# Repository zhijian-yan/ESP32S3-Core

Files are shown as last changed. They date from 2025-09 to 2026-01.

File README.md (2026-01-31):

<h1 align="center">ESP32S3-Core</h1>

<p align="center">
<a href="README.md">English</a> | <a href="README_zh.md">简体中文</a>
</p>

<p align="center">
Core board based on Espressif ESP32-S3 module
</p>

<p align="center">
Prototype verified, schematic and Gerber files included — ready for PCB fabrication!🚀🚀🚀
If you find it useful, please consider giving it a star!☝️
</p>

## Features

* Dual-layer PCB design
* All GPIOs are fully broken out, with pin layout compatible with Espressif official ESP32-S3 development boards
* Onboard 160×80 resolution LCD display, backlight brightness controlled by `GPIO9`
* Onboard TF (microSD) card slot, sharing the same SPI bus with the LCD
* LCD and TF card are connected to a full-speed SPI bus routed via IOMUX, supporting up to `80 MHz` clock
* Onboard WS2812B RGB LED driven by `GPIO38`
* USB-to-UART bridge: CH340K, supporting baud rates up to `2 Mbps`
* 5V pin supports both input and output; USB Type-C interface protected by a Schottky diode
* Compact form factor, all resistors and capacitors use 0402 packages

## Silkscreen Labels

* `RST` : Reset button
* `BOOT` : Boot mode selection button
* `PWR` : Power indicator LED
* `TX` : UART transmit indicator LED
* `RX` : UART receive indicator LED
* `USB` : USB Type-C port for full-speed USB communication
* `COM` : USB Type-C port for UART flashing and debugging

## Pin Configuration

> Note: The LCD and TF card share the same SPI bus

| Function | Signal | GPIO |
|---|---|---|
| LCD | LCD_SCLK | IO12 |
| LCD | LCD_MOSI | IO11 |
| LCD | LCD_CS | IO10 |
| LCD | LCD_DC | IO21 |
| LCD | LCD_RST | IO14 |
| LCD | LCD_BL | IO9  |
| TF Card  | TF_SCLK | IO12 |
| TF Card  | TF_MOSI | IO11 |
| TF Card  | TF_MISO | IO13 |
| TF Card  | TF_CS | IO8  |
| UART | TXD0 | IO43 |
| UART | RXD0 | IO44 |
| USB | USB_D- | IO19 |
| USB | USB_D+ | IO20 |
| RGB LED  | RGB | IO38 |

## Hardware Overview

### Board Photo

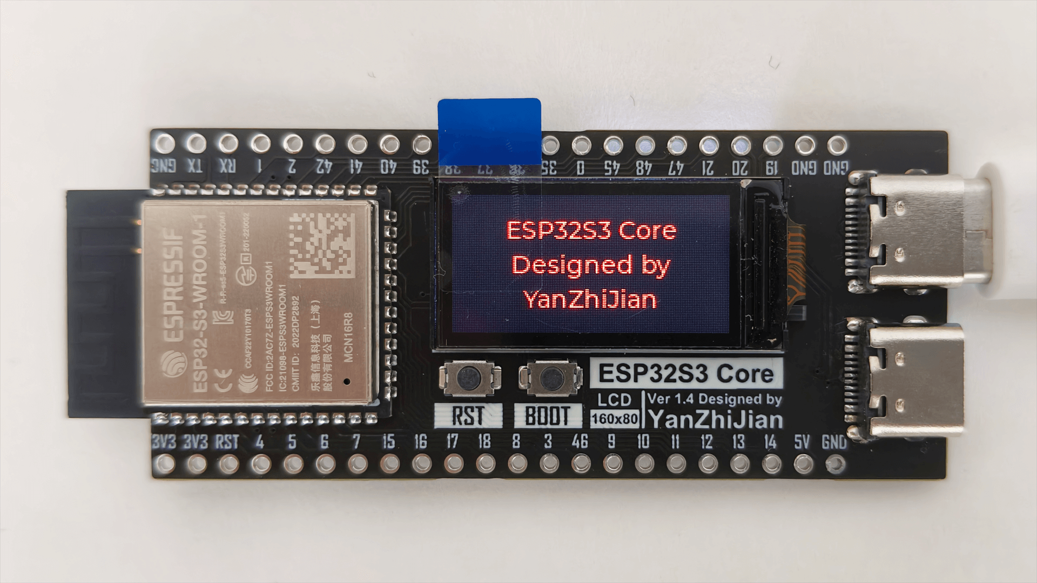
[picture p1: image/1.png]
Board Photo


### Schematic

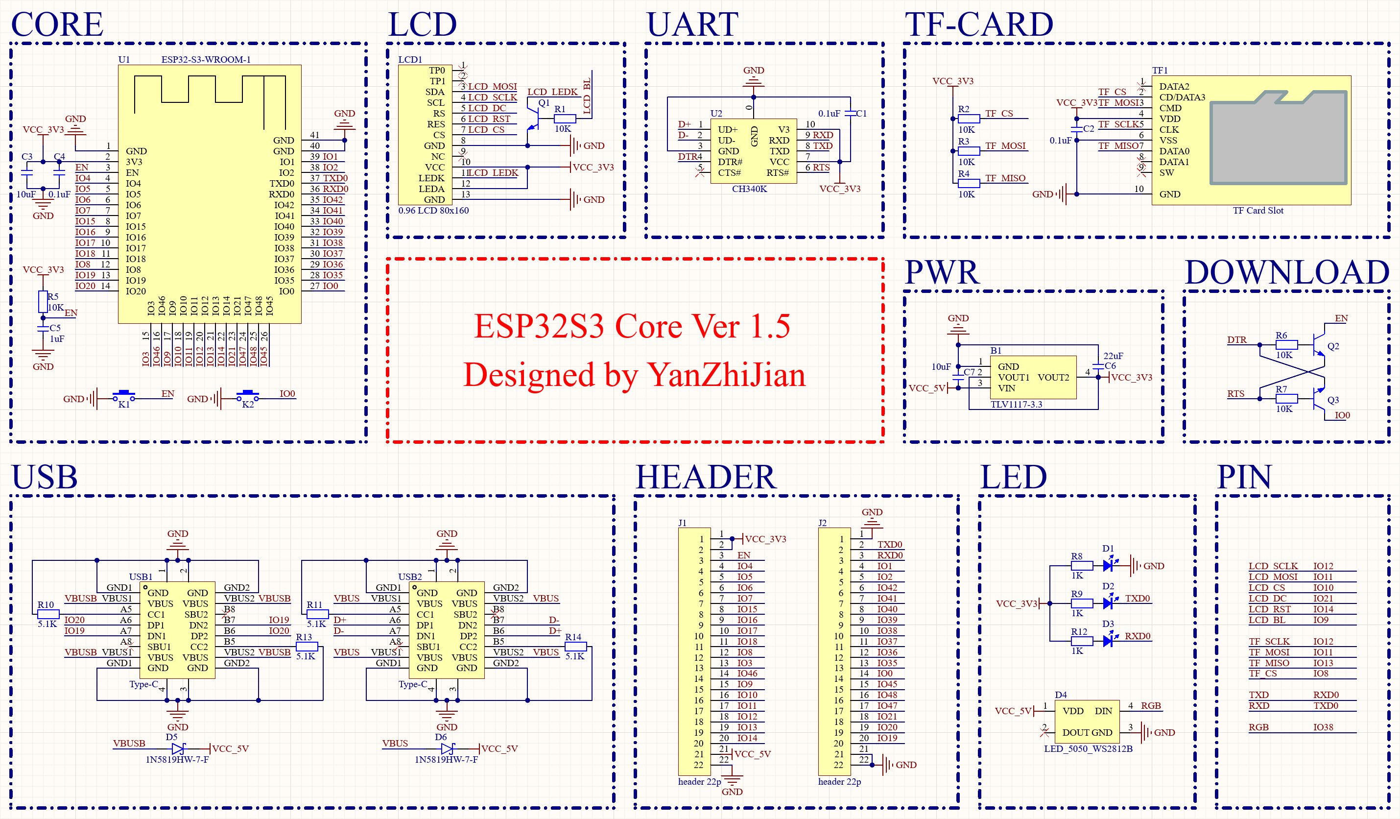
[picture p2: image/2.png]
Schematic


### PCB Layout

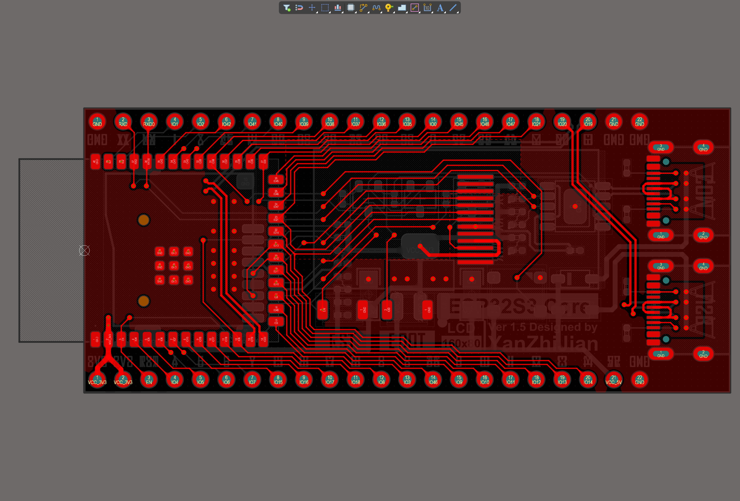
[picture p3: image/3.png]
Top Layer
  
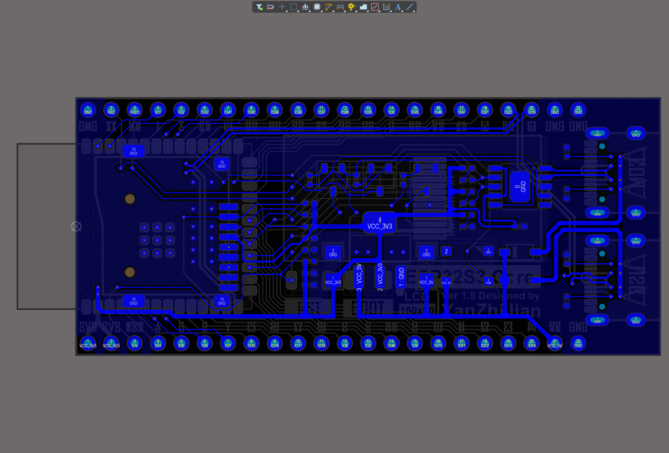
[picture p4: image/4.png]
Bottom Layer


### 3D Model

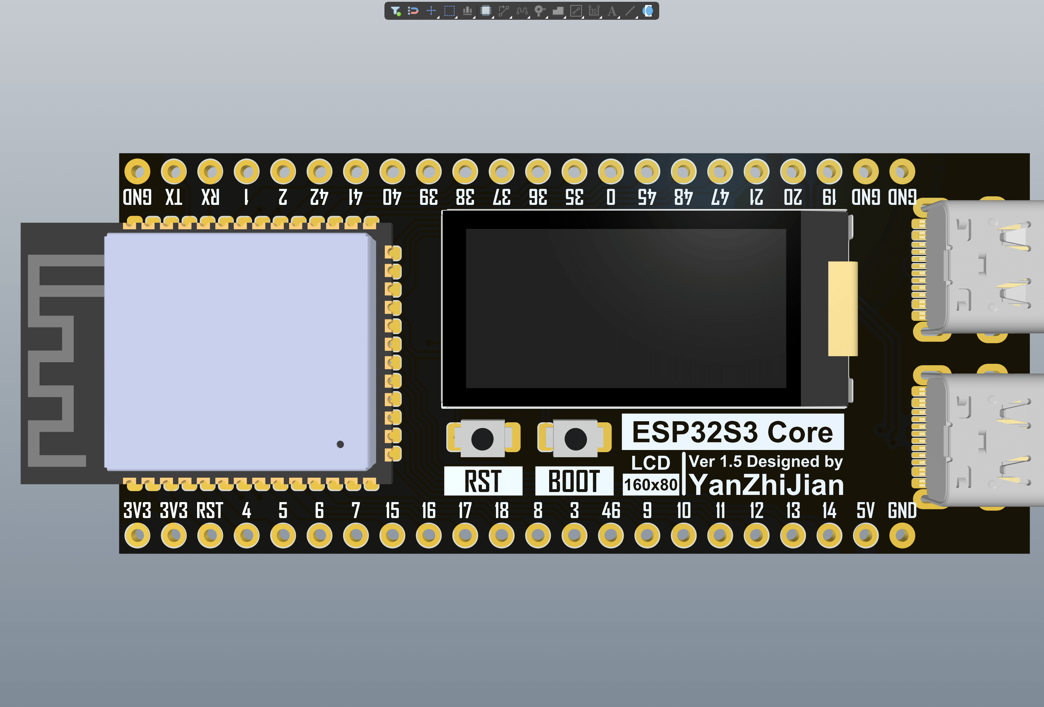
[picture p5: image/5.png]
Top View
  
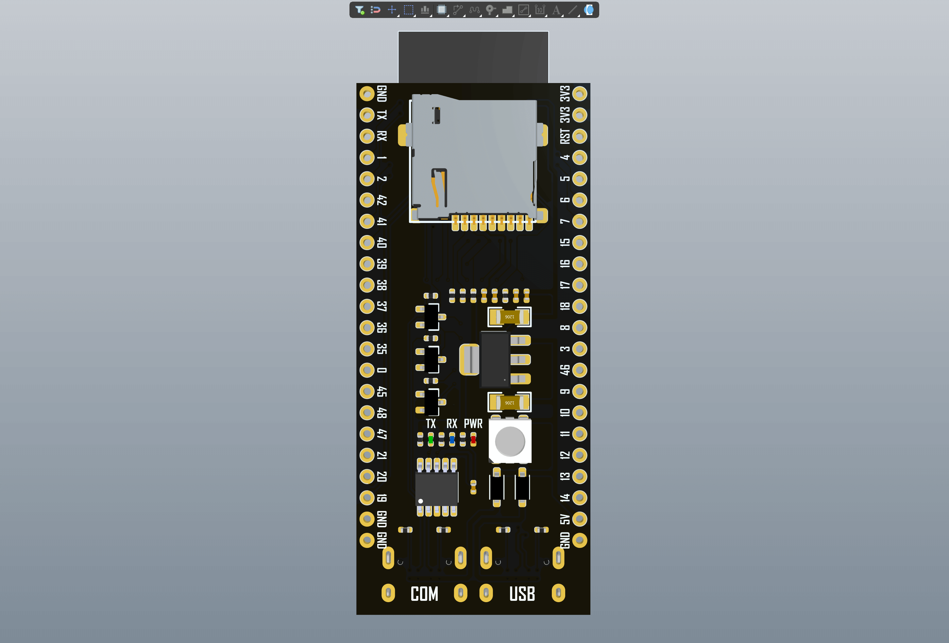
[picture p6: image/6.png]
Bottom View


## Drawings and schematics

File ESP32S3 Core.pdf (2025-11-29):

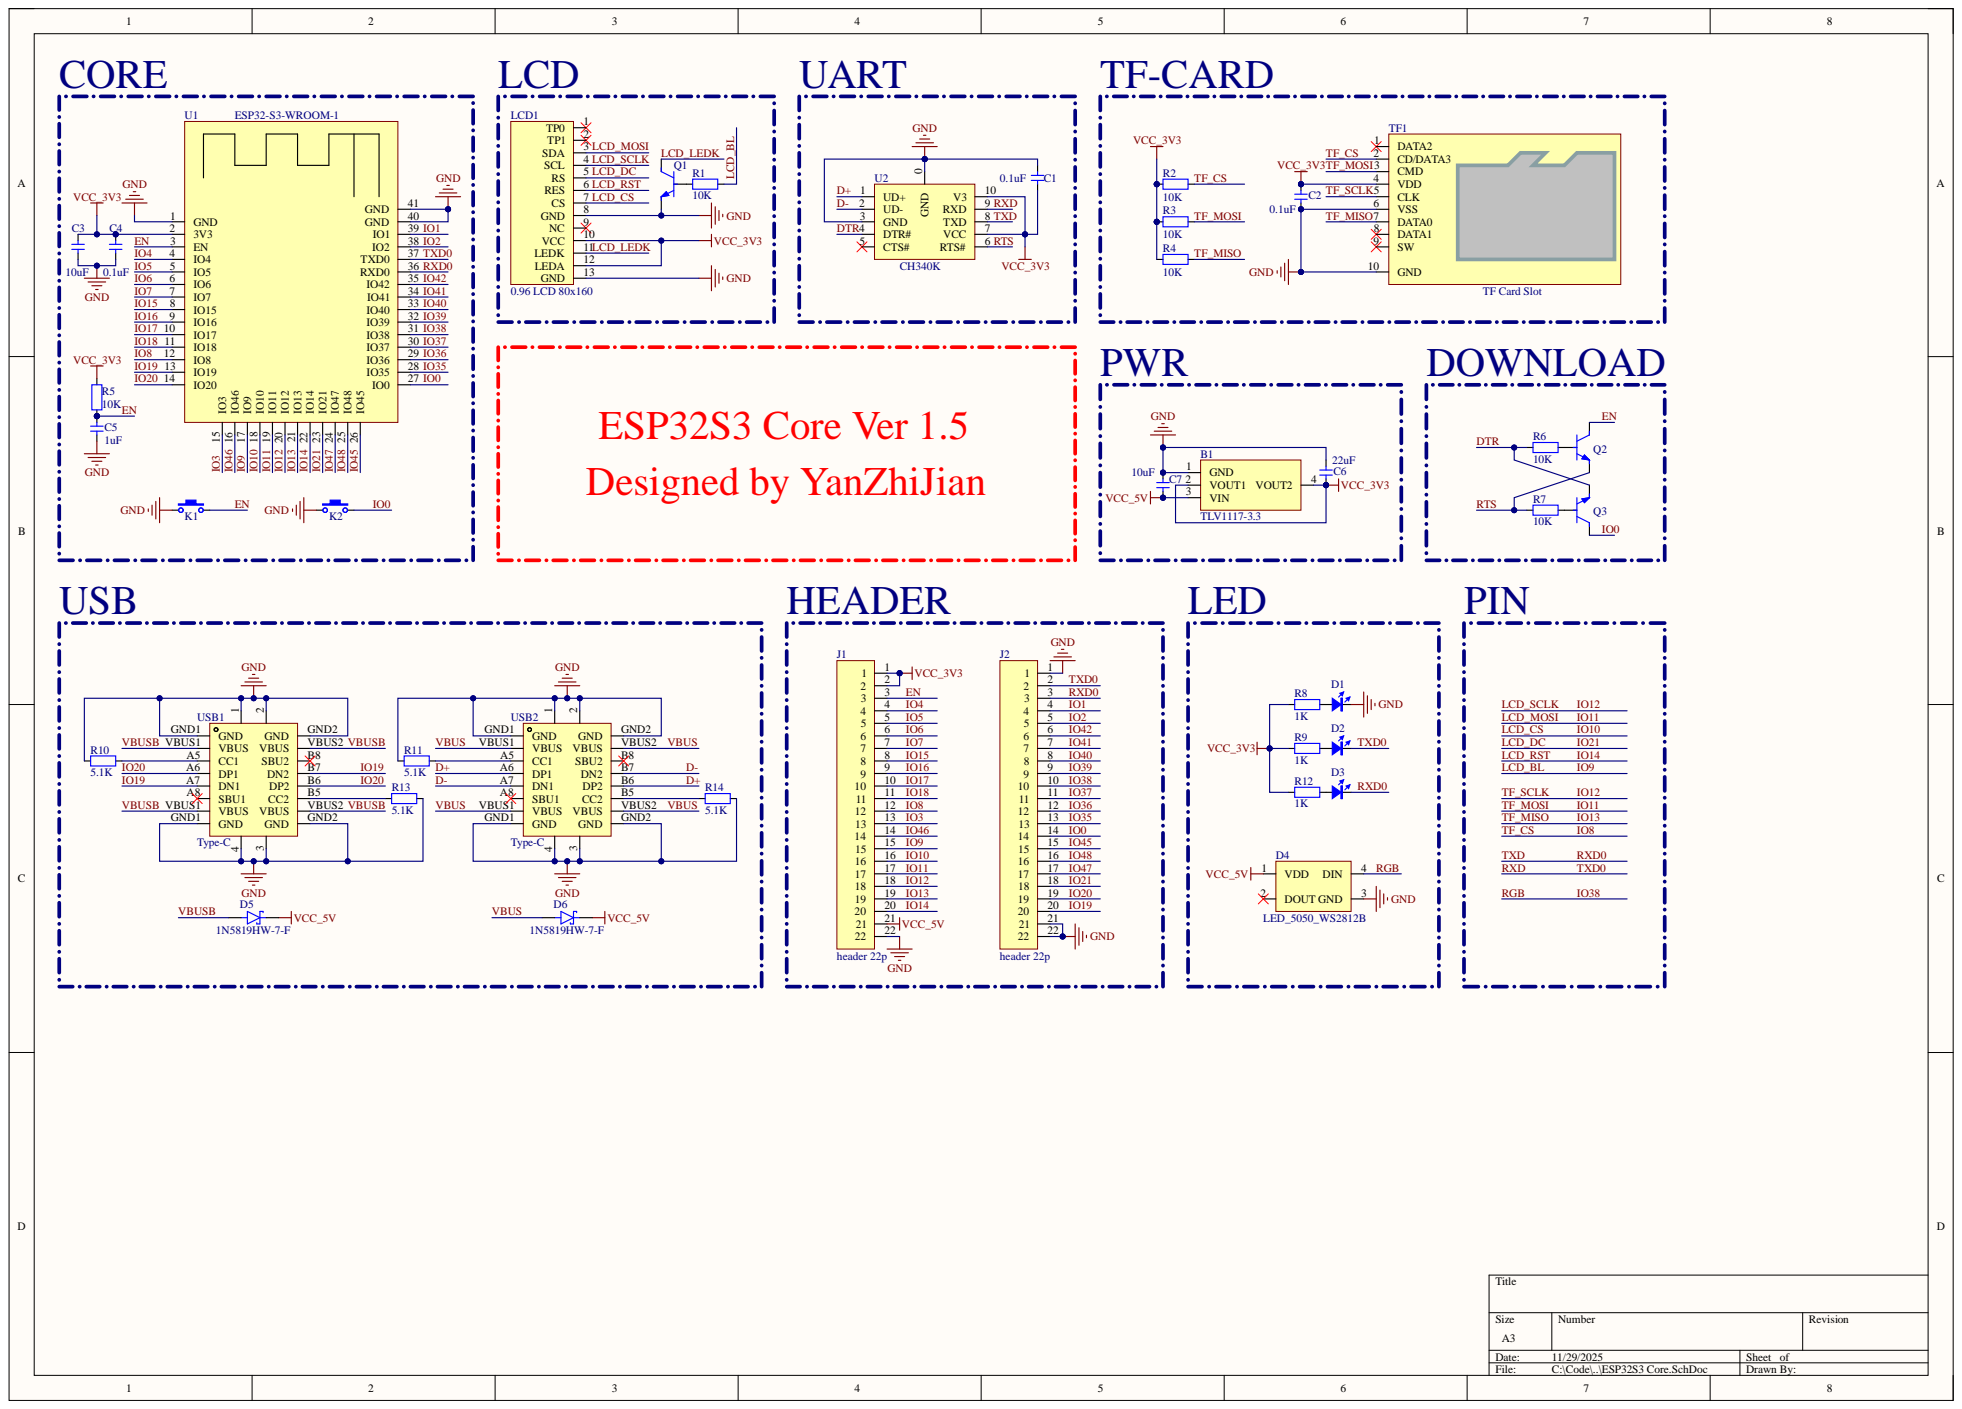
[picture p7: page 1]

B 1
1 | GND VOU T 1 T 2

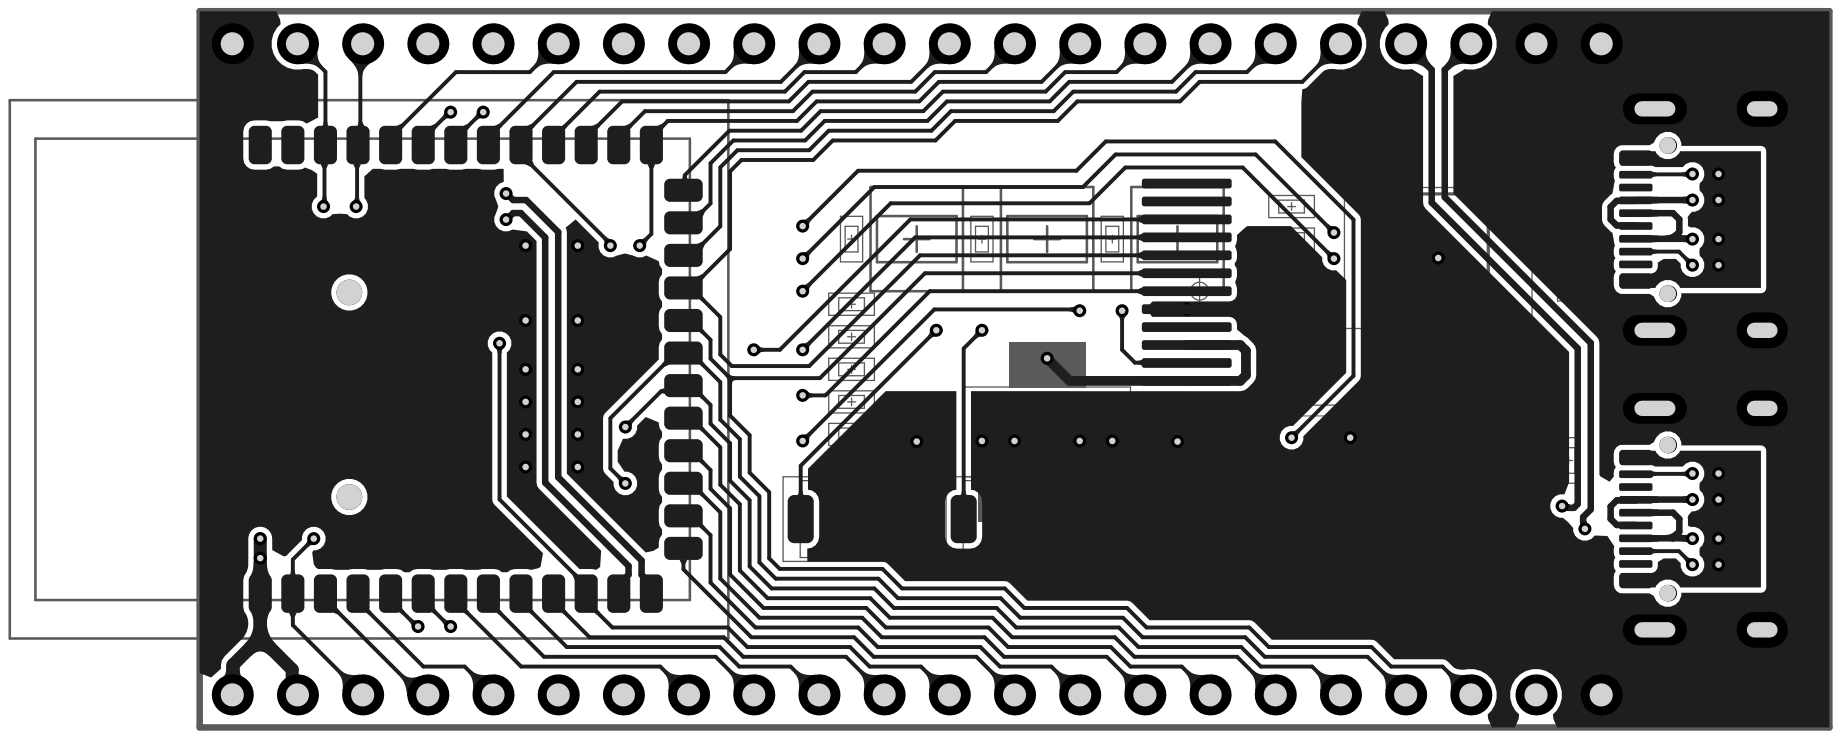
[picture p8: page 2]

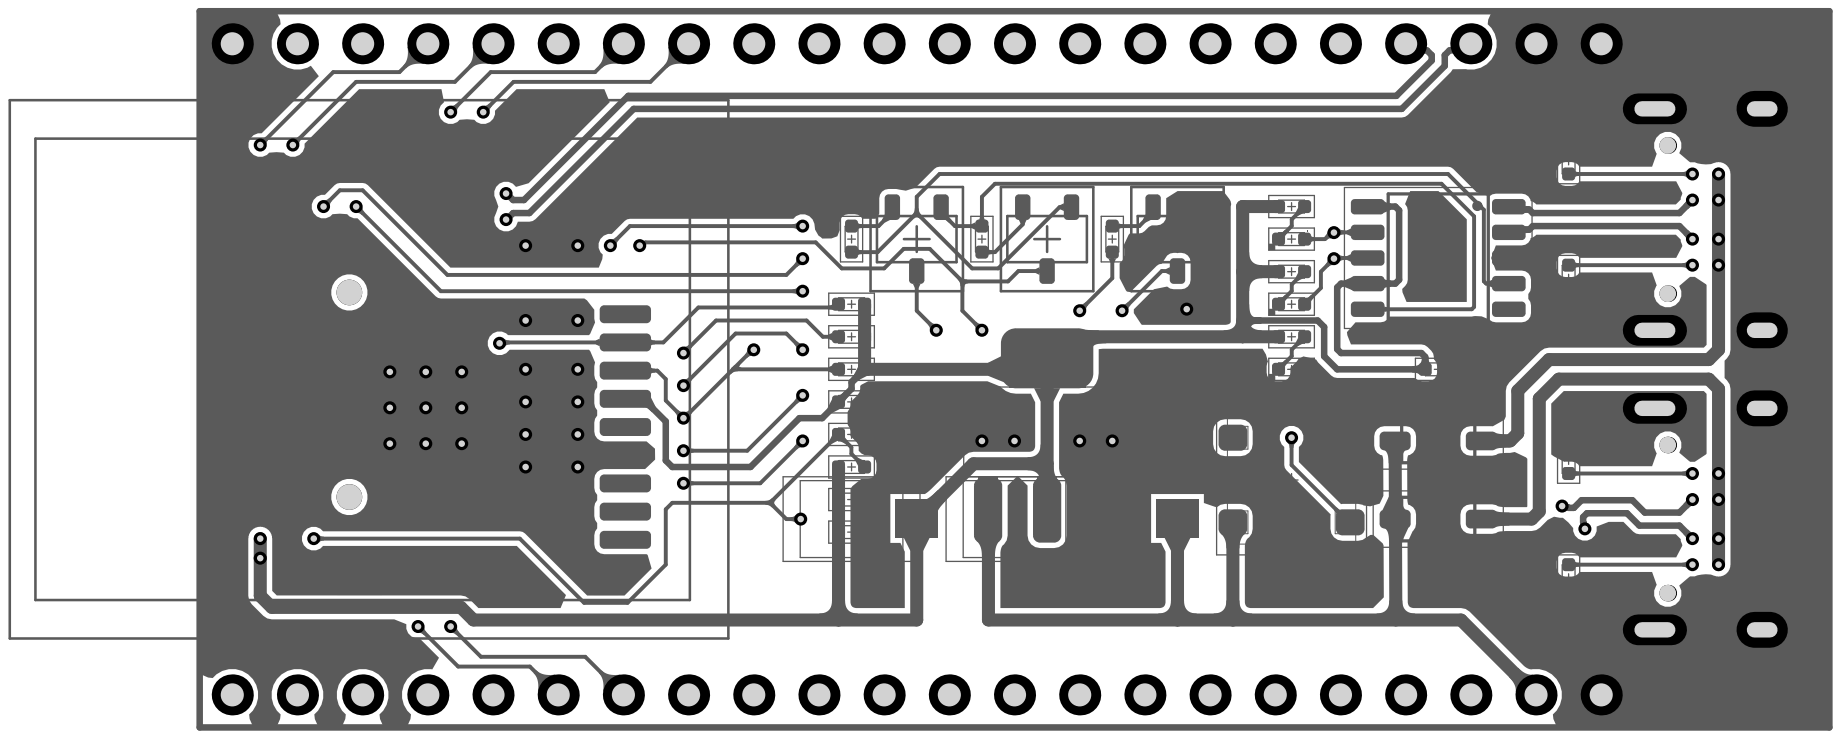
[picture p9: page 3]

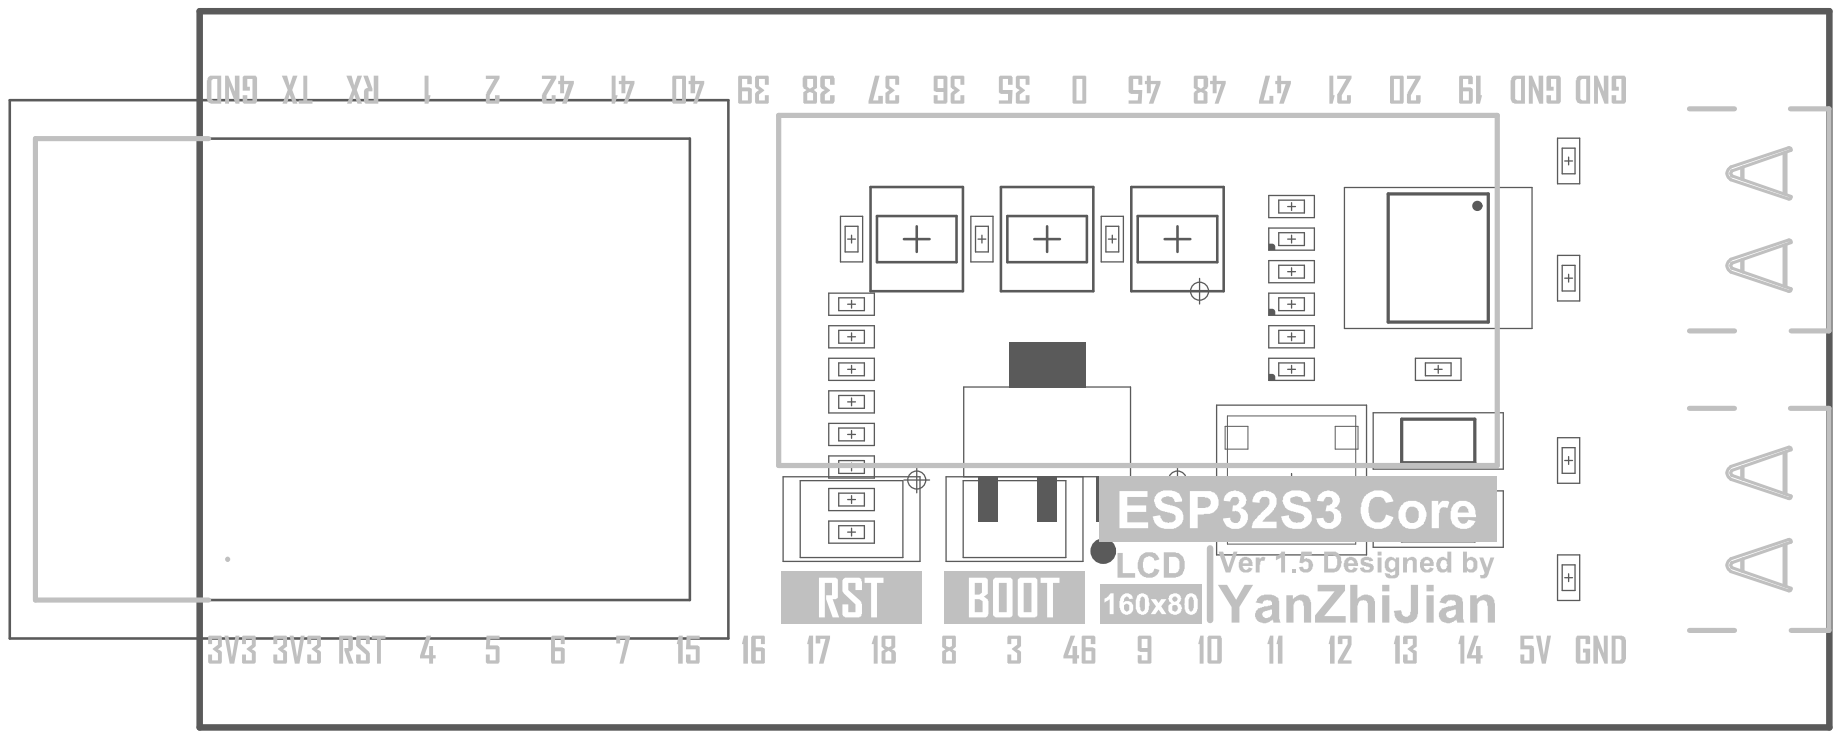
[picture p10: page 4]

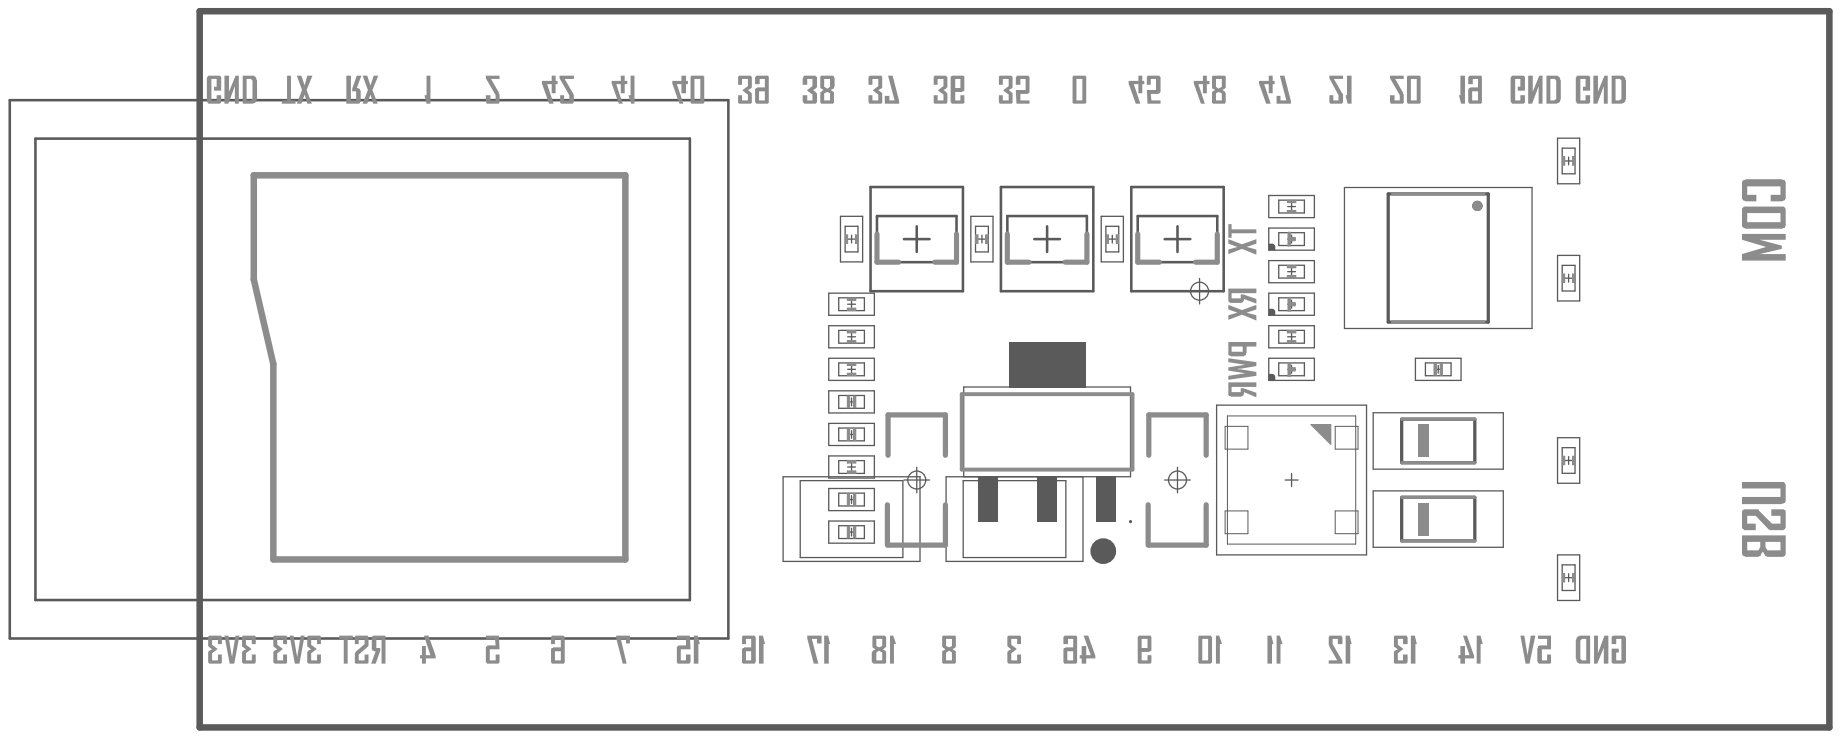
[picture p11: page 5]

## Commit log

2025-11-07 Updated to version 1.5
    Modify the serial communication voltage of CH340K to 3.3V and optimize the power supply path.
    [ESP32S3 Core.PcbDoc, ESP32S3 Core.PrjPcb, ESP32S3 Core.SchDoc]
2025-11-29 Update schematic
    [ESP32S3 Core.PcbDoc, ESP32S3 Core.PrjPcb, ESP32S3 Core.SchDoc]
